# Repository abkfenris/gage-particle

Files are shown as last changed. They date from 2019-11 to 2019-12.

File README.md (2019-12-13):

# gage-particle 

Building a river gage using [Particle.io](https://store.particle.io/collections/cellular/products/boron-lte-kit) with to incorperate what I learned during my last attempt at building one.

## Why

It turns out to be very expensive to have the USGS run a river gage (due to Congressionally set managment standards).
This puts setting up a gage on smaller watersheds well past the point of being reasonable for groups of paddlers or environmental organizations to set one up.

My goal with this project is to develop a low cost gage that is simple enough for most groups of paddlers or environmental organizations to be able to set one up.

## Current status

Under development. Somewhere between in pieces on my desk, hanging off my porch, or hanging off a sea wall to get a tidal water signal for sensor testing.

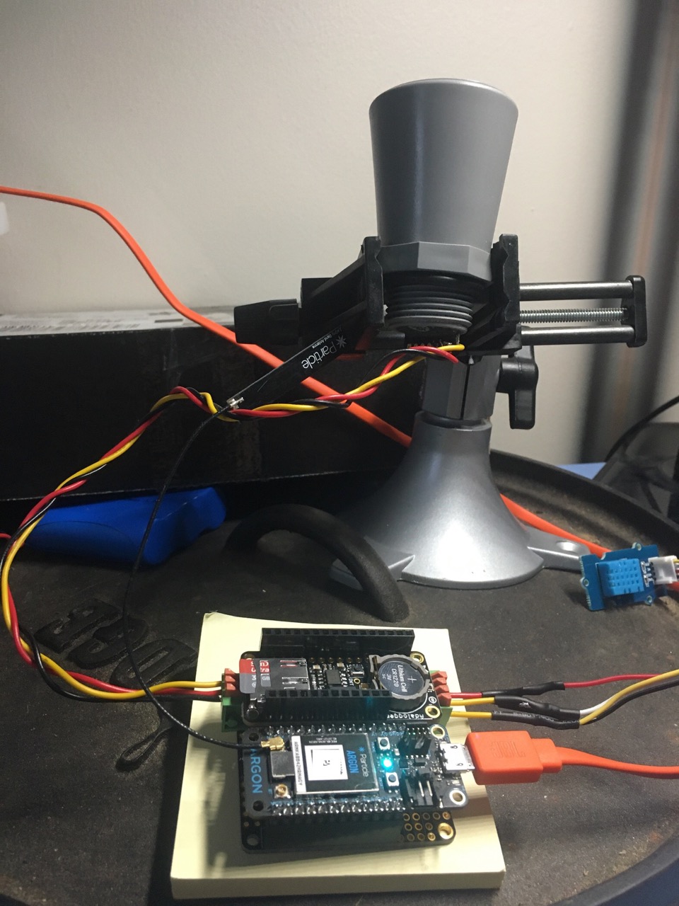
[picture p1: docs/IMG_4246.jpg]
Running on my desk


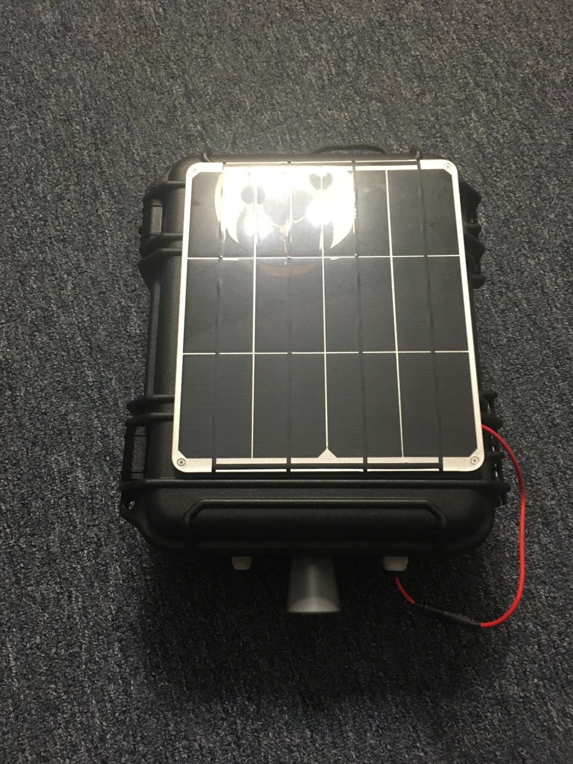
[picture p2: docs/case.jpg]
Case


## Learnings from last time

Some of the things that I learned last time.

- Power is hard, reliability of single board computers in the Maine (and generally wherever interesting rivers can be found) elements is even harder.
- Use a third party data system until the device is reliable. No need for dealing with having your own server down while trying to debug the device.
- Paying for a system with integrated networking and power is worth it.
- Don't try to develop the server and the device at the same time from scratch.

## What is all this hardware

Scary

Also:

- Particle.io [Boron (cellular)](https://store.particle.io/collections/cellular/products/boron-lte-kit) or [Argon (wifi)](https://store.particle.io/collections/wifi/products/argon-kit). - \$59.00 or 35.00
  - The particles are cloud connected microcontrollers with built in cellular or wifi. They run a variant of C++ called wiring that was popularized by Arduino.
  - What makes them really nice is the cloud control and update interface that Particle.io runs.
    You can send commands, check variables, and recieve events remotely.
    Events can be forwared via webhooks to other servers.
    You can also remotely flash the hardware!
  - They also deal with cell carriers, so you can have a single plan that works for devices worldwide. \$2.99 a month for 3 MB of data. Doesn't seem like much, but they have done a lot of work to minimize data overhead, so that can actually go a relatively long way.
  - Much lower power than a single board computer like a Raspberry Pi or Beaglebone Black (what I developed the previous generation of gage with). It also includes a lithium battery charger, so the gage will hopefully not need an external charge controller.
  - They also have a built in mesh communication system. I'm not planning on taking advantage of it in the near term, but it opens up some interesting possibilities. Especially with ho putting a gage near enough to a river might put the device in a cellular dead zone, you can relay from the sensing device to one that has a cellular connection...
  - The mesh system can also be used as a Bluetooth Low Energy perpherial. I envision setting it up to log data via BLE UART virtual serial so that anyone can connect their phone and see the current reading.
- [Adafruit FeatherWing Real Time Clock + SD data logger](https://www.adafruit.com/product/2922) - \$8.95
  - Particle's mesh series of boards are built to [Adafruit's Feather standard](https://learn.adafruit.com/adafruit-feather/overview), therefore we can use most boards that follow the standard.
  - This board provides a real time clock with it's own backup battery and a microSD slot.
  - The microSD is used to store device logs, and data.
  - The real time clock is used to keep track of time for the Particle as it doesn't have a backup clock for when it's shutdown or in sleep mode.
  - Requires a [CR1220](https://www.adafruit.com/product/380) coin cell battery (~$.95) and a [microSD card](https://www.adafruit.com/product/1294) (~$9.95).
- [Adafruit Feather Tripler](https://www.adafruit.com/product/3417) - \$8.50
  - Allows the Particle board and Adafruit logger to be mounted side by side. It also gives some prototyping space for wiring up sensors.
  - I'm current using some [Terminal Blocks](https://www.adafruit.com/product/2137) (~\$1.55) to connect the sensors to the board.
- [Maxbotix MB7386 NRXL-MaxSonar-WRLT](https://www.maxbotix.com/Ultrasonic_Sensors/MB7386.htm) ultrasonic distance sensor - \$119.95
  - We have to find out how far away the water is somehow right? This way our sensor doesn't have to be in the water and the gage can be self contained.
  - This sensor works from .5 to 10 meters, and is supposed to be pretty good for water.
  - It's weather sealed (important for the parts of the device that will be outside the box).
  - It communicates over TTL serial, analog, and pulse width modulation. TTL serial means that we can read the exact millimeters the sensor is picking up instead of trying to calculate voltage differences (analog).
  - [Mounting hardware](https://www.maxbotix.com/Ultrasonic_Sensors/MB7950.htm) (\$3.00) for mounting the sensor in a drilled out hole and keeping it water tight.
- [Benewake TFMiniPlus](https://www.robotshop.com/en/benewake-tfmini-plus-micro-lidar-module-uart-i2c-12-m.html) LIDAR distance sensor - \$44.90
  - A new method to compare to the output of the ultrasonic sensor.
  - It may not work as well on a water surface as the ultrasonic sensor.
- Temperature sensor - currently a hacked together Seeed Studio Grove sensor as I had it laying around.
  - Will probably switch to [AM2303 temp-humidity sensor](https://www.adafruit.com/product/393) (\$15.00) or similar.
  - A temperature sensor should not be neccessary for operation, however lithium batteries are not the largest fans of being charged in very cold or very warm temperatures, so it would be useful to manage charging if those temperatures are encountered.
- [3.7V 6600 mAh Lithium Ion Battery](https://www.adafruit.com/product/353) - \$29.50
  - While the Particle Boron and Argon kits include batteries, this one has a good bit more oomph. If we're hoping to record and transmit data overnight, then a larger battery will hopefully leave us with a bit more usable charge in the morning.
- [Voltaic 9 Watt Solar Panel](https://voltaicsystems.com/9-watt-panel/) - \$79.00
  - I have two of these panels left over from my previous experiment which needed a lot of power. I have heard of folks using 1 watt panels with the Particle mesh devices.
  - Also needs a [microUSB adapter](https://voltaicsystems.com/f3511-microusb/) (\$6.00).
- Waterproof storage box
  - Previously I was using a [sprinkler system box](https://www.amazon.com/gp/product/B000VYGMF2/) (~\$33.48) that is very oversized for the Particle board, but it was sized for 12V battery and charging system for the previous incantation of the gage. Nicely, it does have two predrilled ports, one that is the right size for the ultrasonic sensor.
  - Probably could use some simplier outdoor electrical boxes too.
  - Now I'm using a [Husky Plastic Tool Box](https://www.homedepot.com/p/Husky-13-5-in-Plastic-Tool-Box-in-Black-2019-002/309211038) (~\$25.00) that is a Pelican case knockoff.

Currently the parts add up to around \$450 if you already have soldering, cables, and other random (wood) parts laying around for mounting.

## Software & Services

The device depends on the [Particle cloud console](http://console.particle.io) (free with device/cell plan) for management and communication.
From there data can be forwared to other services like Ubidots (see the [test device dashboard](https://industrial.ubidots.com/app/dashboards/public/dashboard/8-TRHCH-qfrA_7u0CV7Xc-4hAHc)).

The device itself runs a C++ variant called Wiring that was popularized by Arudinos.

Particle has a few [tutorials](https://docs.particle.io/tutorials/device-os/device-os/), but perhaps most useful is the [device firmware referenece](https://docs.particle.io/reference/device-os/firmware/boron/).

### Device Software

[`gage-particle.ino`](src/gage-particle.ino) is our devices's entrypoint.
I've tried to keep it's file structure as simple as possible so that you can build up an understanding of different parts as you need it.

However there are some key things to know.

#### Structure

I've largely followed the [`Runnable`](src/runnable.h) class structure found in [Arduino the Object Oriented Way](http://paulmurraycbr.github.io/ArduinoTheOOWay.html).
That way the publicly exposed interface for most classes follows the primary `constructor`, `setup()` `loop()` pattern that the main file follows, and internal details on how a sensor works or how often data is sent to the Particle console are taken care of by the internal structure of each class.

##### [`Runnable`](src/runnable.h)

A [`Runnable`](src/runnable.h) class has at least a `void setup()` and a `void loop()`. Almost everything inherits from `Runnable`.

##### [`SettingManager`](src/settings_manager.h)

[`SettingManager`](src/settings_manager.h) takes care of retrieving and persisting settings data to the `EEPROM` when the device is powered off. It also sets up [`Particle.function()`](https://docs.particle.io/reference/device-os/firmware/boron/#particle-function-)s allowing settings to be changed from the Particle Console.

##### [`NetworkManager`](src/network.h)

[`NetworkManager`](src/network.h) takes care of managing cellular or wifi status.

##### [`DataLogger`](src/logging/data_logger.h) and [`DataLog`](src/logging/data_logger_manager.h)

[`DataLogger`](src/logging/data_logger.h) and [`DataLog`](src/logging/data_logger_manager.h) expand upon the design of the system [`LogHandler` and `Log`](https://docs.particle.io/reference/device-os/firmware/boron/#logging).

`DataLogger` subclasses provide mechanisms to log messages or key/value pairs to various systems (Particle console, Serial, Ubidots, microSD, Bluetooth Low Energy UART). A logger may transmit data immediately, or buffer it.

`DataLogger`s expose 4 key methods.

- `void add_value(char *key, float value)` - Add a named data point, like a sensor reading.
- `void log_message(String message)` - Add a message for output.
- `void persist_values()` - If a logger buffers values (say in a `std::map`) save the latest values immediately. Usually called from `DataLogger::loop()` rather than directly.
- `void update_settings(struct Settings settings)` - Allows logger internal settings to be updated if the general settings have been changed.

`DataLog` is a global/singleton manager that distributes data out to registered `DataLoggers`.

`DataLog` should be imported by indivudal sensors or other classes or functions looking to persist data.

`DataLog` extends the functionality of `DataLogger` (which it passes to registered loggers) with `add_logger(DataLogger &logger)` to register the loggers.

#### [`Sensor`](src/sensor/sensor.h)

[`Sensor`](src/sensor/sensor.h)s follow the `Runnable` structure, and extend it with a `float value()` method that immediately returns the key value that it is monitoring.

Mainly however `Sensor`s use `DataLog` within their loops to directly log values as they are read, and individual loggers control what to do with those values.

#### Dependencies

There are a few external dependencies.

- [provideyourown/statistics](https://github.com/provideyourown/statistics/tree/45e5e3d11cd8c80b85f7337c4cc4f5037ef66d51) soon to be replaced with [dndubins/QuickStats](https://github.com/dndubins/QuickStats) for providing sensor data statistical analysis (allowing a mean or median to be taken rather than just the latest value).
- [Seeed-Studio/https://github.com/Seeed-Studio/Grove_Temperature_And_Humidity_Sensor](https://github.com/Seeed-Studio/Grove_Temperature_And_Humidity_Sensor) for the current temperature sensor.
- [rickkas7/PublishQueueAsyncRK](https://github.com/rickkas7/PublishQueueAsyncRK) for pushing in the background, and persisting publish backlogs when there is no connection. _Not implemented yet._
- [rickkas7/JsonParserGeneratorRK](https://github.com/rickkas7/JsonParserGeneratorRK) for forming Ubidots compatible publish JSON.
- [rickkas7/SDCardLogHandlerRK](https://github.com/rickkas7/SdCardLogHandlerRK) for logging data to microSD card and avoiding dealing with [SDFat](https://github.com/greiman/SdFat) directly.

#### [Particle.io Functions](https://docs.particle.io/reference/device-os/firmware/boron/#particle-function-)

Various settings controlling the device can be set via the Particle.io console (or via API).

- `settings-ubidots_update_seconds` - Set the number of seconds between sending updates to Ubidots. Defaults to 30 during testing. Should be increased once deployed. Sending `'stop'` should stop updates all together.
- `wifi_add_network` - You can add a new network to the device remotely (when it's already connected to a network it knows). Call the function with `ssid:password` to add the new SSID. Or use `particle serial wifi`.

### Cloud

The gage depends on the Particle Console to operate, and Ubidots can make displaying data much easier.

#### Particle Console

Particle console allows you to see latest events, current device status, and send functions to the device.

As events can be forwarded as webhooks, IFFFT, Google Cloud Functions, AWS Lambda, and a ton of other options with HTTP APIs are options for recieving data.

#### Ubidots

Ubidots offers a [free STEM offering](https://ubidots.com/stem/) which makes for a nice development dashboard.

## Burning fingers (aka soldering)

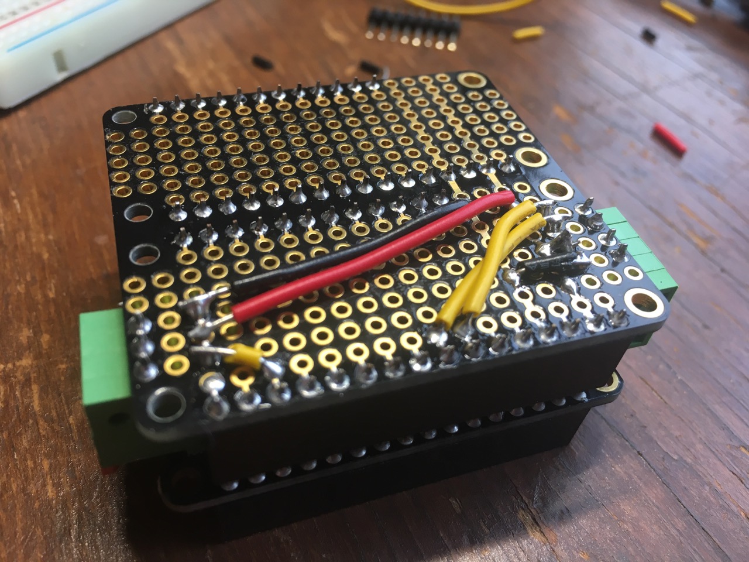
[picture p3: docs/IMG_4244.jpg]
wiring on the Feature doubler


- Port 5 of the ultrasonic sensor is connected to Serial1 rx port
- For the Grove sensor, yellow connects to A2, and white to A3.

## Todo

- Switch to using a median rather than a mean for sensor statistics.
- ~~Use Real Time Clock~~
- ~~Log data to microSD card~~
- Use semi-automatic and ~~threaded~~ system modes
- Manage cellular/wifi connections in `NetworkManager`
- Get it in the field for testing
- Figure out how to sleep the system and for how long
- ~~Track battery state.~~
- If there are too many keys the publish gets truncated

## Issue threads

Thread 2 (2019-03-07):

Sensor

abkfenris, 2019-03-07:
[Maxbotix MB7386 HRXL](https://www.maxbotix.com/Ultrasonic_Sensors/MB7386.htm) uses TTL serial.

- [Serial reference](https://docs.particle.io/reference/device-os/firmware/argon/#serial)
- [Serial tutorial](https://community.particle.io/t/serial-tutorial/26946)
- [Trouble with Serial1](https://community.particle.io/t/having-trouble-reading-a-string-with-serial1-from-a-maxbotix-mb7092-rangefinder/16738)

abkfenris, 2019-11-22:
Update rate is 6 hz.

abkfenris, 2019-11-22:
Closed with 3fd39b604dbe9df86e377ee403ef1e0637543962

abkfenris, 2019-12-01:
https://community.particle.io/t/maxbotix-sensor-and-ttl-serial/36831/13

abkfenris, 2019-12-09:
https://www.maxbotix.com/articles/maxsonar-troubleshooting.htm

Closed 2019-11-22.

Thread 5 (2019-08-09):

Sampling

abkfenris, 2019-08-09:
Try using a mean of modes to average sensor data.

abkfenris, 2019-11-22:
That might be slow at 6 hz. Maybe just use the statistics library and additionally log the standard deviation.

abkfenris, 2019-11-22:
Closed with 3fd39b604dbe9df86e377ee403ef1e0637543962

abkfenris, 2019-11-24:
Switch to [QuickStats](https://github.com/dndubins/QuickStats) and use the median for a smoother value than the mean.

abkfenris, 2019-12-06:
https://community.particle.io/t/hx711-produces-noisy-data-with-boron/49974/6

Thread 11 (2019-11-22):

Power

abkfenris, 2019-11-22:
https://community.particle.io/t/boron-one-year-battery-life-project/52343/21

abkfenris, 2019-11-22:
https://community.particle.io/t/cold-weather-and-lipo-charging/53277

abkfenris, 2019-11-22:
https://docs.particle.io/reference/device-os/firmware/argon/#sleep-sleep-

abkfenris, 2019-12-06:
- https://community.particle.io/t/preliminary-0-9-0-boron-lte-current-consumption-in-sleep-modes-measurements/47969/49
- https://community.particle.io/t/wakeon-ri-in-sleep-network-standby/43756/25
- https://community.particle.io/t/system-sleep-network-standby-mode/29432/3
- https://community.particle.io/t/data-usage-no-ack-and-sleep-network-standby-help/25600/3
- https://community.particle.io/t/electron-using-sleep-network-standby-and-sleep-disable-wkp-pin/50077/2

abkfenris, 2019-12-06:
- https://community.particle.io/t/current-consumption-and-sleep-modes-boron/45612/61
- https://blog.voltaicsystems.com/solar-charger-for-particle-boron-with-cat-m-1/
- https://community.particle.io/t/low-power-boron-lte-using-the-en-pin/46257
- https://community.particle.io/t/boron-gpio-provides-less-current-than-electrons-gpio/46647/15

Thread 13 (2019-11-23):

Another Gage

abkfenris, 2019-11-23:
https://www.hackster.io/jasperpons/river-level-monitoring-for-kayakers-and-flash-flood-warning-d7ab93

abkfenris, 2019-12-06:
https://community.particle.io/t/looking-for-volunteers-to-create-a-project/47339/50

abkfenris, 2019-12-06:
https://community.particle.io/t/project-log-ultrasonic-flood-level-sensor-using-photon-i2cxl-maxsonar-mb7040/17971/19

abkfenris, 2020-04-09:
https://www.hackster.io/mawrey/tide-and-meteorological-station-03b26e

abkfenris, 2021-01-24:
- https://www.maxbotix.com/articles/river-flood-monitoring-with-ultrasonic-sensors.htm
- https://www.maxbotix.com/articles/ultrasonic-level-lorawan-sensor.htm
- https://www.maxbotix.com/articles/iot-water-level-monitoring.htm
- https://www.maxbotix.com/articles/high-performance-solar-power-for-iot.htm
- https://blog.voltaicsystems.com/tide-monitoring-with-ultrasonic-sensors/
- https://blog.voltaicsystems.com/solar-powered-river-gauge-with-particle/
- https://www.hackster.io/mawrey/tide-and-meteorological-station-03b26e#code
-

abkfenris, 2021-04-01:
- https://oceanographyforeveryone.com/project/openctd/
- Water Rangers
  - https://mobile.twitter.com/water_rangers
  - https://waterrangers.ca

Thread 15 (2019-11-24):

SDLogger

abkfenris, 2019-11-24:
Currently [`SDLogger`](https://github.com/abkfenris/gage-particle/blob/921977994bfbc03cde8be5e471d87b256124dfe9/src/logging/sd_logger.h) uses [`SdCardPrintHandler`](https://github.com/rickkas7/SdCardLogHandlerRK), which takes care of all the logging and device management for us.

Currently this means that values and messages are being interspersed in the same log files, and the log files aren't identifiable as to when and how they were created.

Hence `/logs/00001.txt` contains values and messages interspersed.

It would be nicer to spilt the values and messages into different folders and have the files named by day.
- `/values/20191124.txt` - For values
- `/logs/20191124.txt` - For messages (and general logging?)

This will probably involve rewriting `SDLogger` to use raw `SDFat`. Some things can be aped from `SdCardPrintHandler` like dealing with calling `sd.begin()` internally.

Maybe having `SDFolderTimePrint` that inherits from `Print` like [`SdCardPrintHandler`](https://github.com/rickkas7/SdCardLogHandlerRK/blob/master/src/SdCardLogHandlerRK.h#L30. Then a separate instance would be opened for each folder. It looks like [`.write()`](https://github.com/rickkas7/SdCardLogHandlerRK/blob/25dcabd016b3a868999550eec6a9d2dae64e6487/src/SdCardLogHandlerRK.cpp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) is the key method to implement for `Print` compatibility.

It might be something worth building into it's own library or contributing back upstream.

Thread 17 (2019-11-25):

LIDAR

abkfenris, 2019-11-25:
[Benewake TFMINI Plus](https://www.robotshop.com/en/benewake-tfmini-plus-micro-lidar-module-uart-i2c-12-m.html)

[Arduino library](https://github.com/budryerson/TFMini-Plus)

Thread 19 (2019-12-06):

Modular sensors

abkfenris, 2019-12-06:
- https://github.com/EnviroDIY/ModularSensors/issues
- https://github.com/EnviroDIY/ModularSensors/pull/94

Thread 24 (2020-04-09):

Random notes

abkfenris, 2020-04-09:
- https://community.particle.io/t/electron-collect-data-every-minute-publish-it-every-15-minutes-with-sleep-better-way-to-do-this/48901/14
- https://github.com/nothings/single_file_libs
- https://pragprog.com/book/jgade/test-driven-development-for-embedded-c
- https://community.particle.io/t/new-boron-based-oceanography-sensor-package-the-openctd-for-boron/49781
- https://twitter.com/FluvialBenthos/status/1205857205636878337
- https://community.particle.io/t/drone-mounted-water-monitoring/54848
- https://community.particle.io/t/how-to-unit-test/2045/2
- https://community.particle.io/t/smoothing-out-sensor-spikes/54399/11
- https://wingman-sw.com/test-driven-development-for-embedded-c-book
- https://wingman-sw.com/papers/titles

abkfenris, 2021-01-24:
- https://github.com/chipmc/Cellular-Environment
- https://github.com/chipmc/Cellular-Pressure-Next
-

abkfenris, 2021-07-03:
- https://www.maxbotix.com/articles/noise-temperature-sensor-operation.htm
- https://www.maxbotix.com/tutorials1/035-maxsonar-troubleshooting-guide.htm
- https://www.maxbotix.com/Ultrasonic_Sensors.htm?swoof=1&pa_application=river-level&outputs=ttl
- https://sentientthings.com/products/weather-station-and-level-adapter
- https://sentientthings.com/products/iot-node
- https://github.com/snovalleypa/SVPA-FloodSensor-2016/blob/master/firmware/checkRange.cpp
- https://www.hackster.io/mawrey/tide-and-meteorological-station-03b26e
- https://www.hackster.io/mawrey/solar-powered-cellular-weather-station-e5a3ed
- https://www.hackster.io/chipmc/particle-electron-carrier-for-outdoor-iot-applications-40ed52
- https://www.hackster.io/Dan/particle-photon-weather-station-462217
- https://community.particle.io/t/what-very-cool-projects-did-you-come-across/58736
- https://community.particle.io/t/project-log-ultrasonic-flood-level-sensor-using-photon-i2cxl-maxsonar-mb7040/17971/17
- https://www.envirodiy.org/forum/environmental-sensors/
- http://toms-wow.blogspot.com/2015/01/open-source-crowd-source-stream-gauge.html
- https://svpa.us/floodzilla-gage-network/
- https://www.envirodiy.org/ultrasonic-water-depth-sensor/
- https://community.particle.io/t/project-log-ultrasonic-flood-level-sensor-using-photon-i2cxl-maxsonar-mb7040/17971
- https://static1.squarespace.com/static/55cba7c2e4b04639c1e746a8/t/588bb49cd1758e8e6949e0f8/1485550765226/Flood+Network+Detail.pdf
- https://www.envirodiy.org/topic/flood-network-level-sensor-network/
- https://www.envirodiy.org/topic/water-monitoring-in-remote-locations-with-a-solar-particle-electron/
- https://wikiwatershed.org/monitor/
- https://www.maxbotix.com/build-industrial-volume-presence-reader-maxbotix-ultrasonic-sensor-esp32.htm
- https://news.ycombinator.com/item?id=24708345
-

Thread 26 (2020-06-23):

Charging issues

abkfenris, 2020-06-23:
- https://community.particle.io/t/boron-xenon-argon-carrier-for-outdoor-applications/48750
- https://community.particle.io/t/boron-solar-charging-with-1-5-0-pmic-issue/55602
- https://community.particle.io/t/boron-devices-stop-charging-deviceos-1-5-0/55925
- https://community.particle.io/t/help-needed-pmic-settings-and-string-variable-corruption/36905
- https://docs.particle.io/reference/device-os/firmware/boron/#charge-timer-control-reg

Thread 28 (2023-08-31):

Things to explore

abkfenris, 2023-08-31:
- https://github.com/pocc/pre-commit-hooks
- https://github.com/eloquentarduino/EloquentArduino
- https://blog.wokwi.com/
- https://codepal.ai/code-reviewer/arduino
- https://arduino.github.io/arduino-lint/1.2/
- https://www.codacy.com/quality
- https://coderabbit.ai/
- https://www.codiga.io/
- https://metabob.com/
- https://codeclimate.com/quality
- https://deepsource.com/pricing
- https://www.codefactor.io/
- https://docs.particle.io/firmware/low-power/wake-publish-sleep-cellular/
- https://community.particle.io/t/boron-is-daily-system-reset-good-hygiene/64696
- https://community.particle.io/t/design-pattern-advice/64873
- https://community.particle.io/t/trying-to-extend-battery-life-on-boron/64077
- https://community.particle.io/t/here-s-how-to-share-data-from-particle-gen-3-devices-using-bluetooth-or-nfc/50701
- https://community.particle.io/t/outdoor-project-case/60468
- https://docs.particle.io/firmware/best-practices/firmware-introduction/
- https://www.hackster.io/dankouba/build-a-weather-station-using-particle-s-monitor-one-25f5ba
- https://community.particle.io/t/using-publishqueueposixrk-with-qspi-and-other-flash/63666
- https://particle.hackster.io/mawrey/tide-and-meteorological-station-03b26e
- https://github.com/brycekellogg/tide-gauge

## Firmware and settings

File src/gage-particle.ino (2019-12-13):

/*
 * Project gage-particle
 * Description: 
 * Author: Alex Kerney (abk@mac.com)
 * Date: 2019-03-06
 */

#include "SdFat.h"
#include "AdafruitDataLoggerRK.h"
#include "SdCardLogHandlerRK.h"

#include "logging/data_logger_manager.h"

#include "settings_manager.h"
#include "network.h"

#include "logging/serial_logger.h"
#include "logging/publish_logger.h"
#include "logging/sd_logger.h"

#include "sensor/grove_temp.h"
#include "sensor/tfmini_plus_lidar_distance.h"
#include "sensor/maxbotix_pwm_distance.h"
#include "sensor/battery_sensor.h"

#define DHTPIN A2                              // temperature sensor pin
const int DEFAULT_UBIDOTS_UPDATE_SECONDS = 30; // Default amount of time between updating Ubidots
char *WEBHOOK_NAME = "Ubidots";                // Webhook name that Ubidots listens to

SYSTEM_THREAD(ENABLED);

// Initialize our key systems

// log general system info to Serial
// Remove to only have messages and values
// Output via DataLog loggers
SerialLogHandler log_handler;

ApplicationWatchdog wd(60000, System.reset);

// MicroSD card access and print logger need to be initialized early,
// And configuration needs to happen at startup, rather than in a
// Specific logger.
SdFat sd;
const int SD_CHIP_SELECT = D5;
SdCardPrintHandler sd_print(sd, SD_CHIP_SELECT, SPI_FULL_SPEED);
STARTUP(sd_print.withMaxFilesToKeep(1000));

RTCSynchronizer rtc_sync;

// Settings manager persists settings to the EEPROM
// and exposes Particle.functions for changing them
SettingManager setting_manager(DEFAULT_UBIDOTS_UPDATE_SECONDS);

// Network manager helps manage Wifi networks on an Argon
NetworkManager network_manager;

// Now for the specific loggers that should be registered to the DataLog
SerialLogger serial_logger;
PublishLogger publish_logger(WEBHOOK_NAME, setting_manager.current_settings());
SDLogger sd_logger(sd_print);

// Finally our sensors
GroveTempSensor tempSensor(DHTPIN);
MaxbotixPWMDistanceSensor distance_pwm;
TfMiniPlusLidarDistanceSensor lidar;
BatterySensor battery;

void setup()
{
  rtc_sync.setup();
  // We first add our loggers in setup, so they are avaliable
  // when other instances run through their setup.
  DataLog.add_logger(serial_logger);
  DataLog.add_logger(publish_logger);
  DataLog.add_logger(sd_logger);
  DataLog.setup();

  // Run through common setups/
  setting_manager.setup();
  network_manager.setup();

  DataLog.log_message("Begin readings!");

  // Finally setup our sensors
  tempSensor.setup();
  lidar.setup();
  distance_pwm.setup();
  battery.setup();
}

void loop()
{
  // First we loop through system level management
  rtc_sync.loop();
  setting_manager.loop();
  network_manager.loop();

  // Then the sensor loops run which allows them to
  // register values with the DataLog before they run
  tempSensor.loop();
  lidar.loop();
  distance_pwm.loop();
  battery.loop();

  // DataLog updates settings of any loggers that may have changes,
  // Then completes the loggers complete their own loops.
  DataLog.update_settings(setting_manager.current_settings());
  DataLog.loop();

  wd.checkin();
}

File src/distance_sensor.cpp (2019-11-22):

#include "math.h"

#include "distance_sensor.h"

#define MINIMUM_READABLE_DISTANCE_MM 500
#define MAXIMUM_READABLE_DISTANCE_MM 9999
#define MINIMUM_BETWEEN_READINGS_MS 200

DistanceSensor::DistanceSensor() : stats(NUMBER_OF_SAMPLES){};

void DistanceSensor::setup()
{
    last_update_ms = millis() - MINIMUM_BETWEEN_READINGS_MS;
    Serial1.begin(9600);
}

void DistanceSensor::loop()
{
    if (millis() - last_update_ms >= MINIMUM_BETWEEN_READINGS_MS)
    {
        int distance_mm = read_sensor();
        if (MINIMUM_READABLE_DISTANCE_MM <= distance_mm && distance_mm < MAXIMUM_READABLE_DISTANCE_MM)
        {
            stats.addData(distance_mm);
            last_update_ms = millis();
        }
    }
}

int DistanceSensor::read_sensor()
{

    while (Serial1.available())
    {
        if (Serial1.peek() == 'R')
        {
            // pop off the R
            Serial1.read();

            char buf[5];

            for (int i = 0; i < 4; i++)
            {
                char data = Serial1.read();
                buf[i] = data;
            }

            int distance_mm = atoi(buf);

            return distance_mm;
        }
        else
        {
            // Not an R, try to clear
            Serial1.read();
        }

        delay(MINIMUM_BETWEEN_READINGS_MS);
    }
}

float DistanceSensor::value()
{
    return stats.mean();
}

float DistanceSensor::std_deviation()
{
    return stats.stdDeviation();
}

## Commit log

2019-11-22 Basic loop reading sensor and repeating to serial
2019-11-22 Add temperature sensor, communication to Ubidots, and restructure into setup and loop commands
2019-11-22 Common Sensor base class
2019-11-22 Add wifi network management, make sure that it will not send data to ubidots if update time is set to 0, and reduce the number of read attempts of the ultrasonic sensor to below it's refresh frequency
2019-11-22 Use statistics to calculate mean for distance sensor, and reduce temperature reads to match the update frequency of the sensor
2019-11-23 Move sensors to their own folder and use DataLog to communicate directly
2019-11-24 Much more documentation, including bill of materials, software structure, what's connected where, todo
2019-11-24 Use System mode thread and real time clock
2019-11-24 Add rotating SD card logger and fix bug with grove_temp loop
    [gage-particle.ino]
2019-11-29 Use PWM to read ultrasonic sensor
2019-12-05 Reduce allowed PWM distance
2019-12-07 Replace ultrasound UART with LIDAR UART
    [Connections.fzz]
